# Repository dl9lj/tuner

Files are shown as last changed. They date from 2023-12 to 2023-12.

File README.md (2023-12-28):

# tuner
wireless remote control for different antenna tuners

Yaesu FC-1000 / FC-800
started with buying a Yaesu Automatic Antenna Tuner FC-1000 w/o control unit. I started with removing the existing controller and thought about to do a replacement with an atmega328p in combination with 3 HC595 shift register. Interface to a laptop pc via uart. I had this setup running (328p firmware in C). But after working with NRF24L01 modules I decided to do the interface wireless. 328p is no longer required but the 595 board can be used.The 3 HC595 are connected via wires and DSUB9 connector to an externel arduino with NRF24L01 module. I wrote a python script with slider and radio buttons. Best band settings were programmed to radio buttons of the script. Later I found out, that my FT-840 has a controller included and I only need to have a cable... But the new setup is more flexible and can be used with any transceiver. 

LDG AT-1000 (2003)
is a asymmetric low-pass 1kW antenna tuner with manual control. Automatic does not really work well and the tuner had some issues with internal EMC. But in general it has good L and C components an uses an Allegro UCN5832 to control the 15 relays. Allegro UCN5832 has an 3-wire interface similar to SPI (data, clock, strobe). Some housings have a hole for D-SUB9 connector, but I have not found an controller option. I have have removed the connection between MC68HC11 and UCN5832 (chokes L11, L12 and L13) and connected UCN5832 with wires to a DSUB9 connector (data, clock, strobe, gnd, 12V). 

Christian Koppler (DL3LAC)
is a symmetric antenna coupler. The main unit contains only L, C and relays and will be controlled with a control unit via a 25-wire cable (16 pins for relays, 7 pins for 12V, 2 pins spare). I have created an interface board with TI TPIC6B595 driver 2s (2p for inductor relays) and 5V Supply. A arduino uno with NRF24L01 will be connected to this interface for receiving control data from the NRF24L01 transmitter.

The NRF24L01 transmitter will be the same for all 3 antenna tuners. NRF24L01 receiver hardware is equal for Yaesu and Christian Koppler. LDG needs a Strobe signal from pin 3 of the arduino. It is not required to build up 3 receiver but a dedicated receiver for each tuner helps to keep the overview. Each receiver requires a separate arduino firmware. 

Software is written very straight forward (no error correction / udp style). GUI does not show the real state after start (only after pushing the button). After start you have to press the "AllOff" button to set everything to zero/off.Terminal shows the output sequence. 

Additional interface hardware is required for Yaesu and Christian Koppler. The schematics for the Yaesu tuner has an wrong order for the relays connected to pin 12 to 19 (RL11,10,9,8,7,6,5,1_2 would be better). Later I have fixed that mistake with jumper wires. In between I have used a python script with LUT to do the correction  but correction in hardware makes programming easier. U1 of the Christian Koppler interface needs a 2nd TPIC6B595 on top (all pins connected except pin18 (nc)) because current output of a single chip is too weak for driving 4 relays in parallel. The board of the LDG Tuner has already the Allegro UCN5832 shift-register which can directly connected to the external arduino. Please check wiring.txt file for connections (is more recent than the existing schematics).

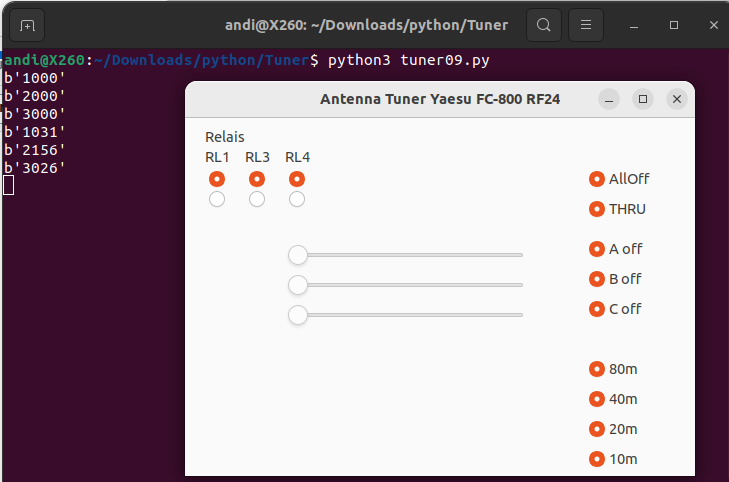
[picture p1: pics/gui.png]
J12


#### GUI
- simple GUI with wxPython
- start with "AllOff" and set all buttons to 0
- output data will be printed on the terminal window

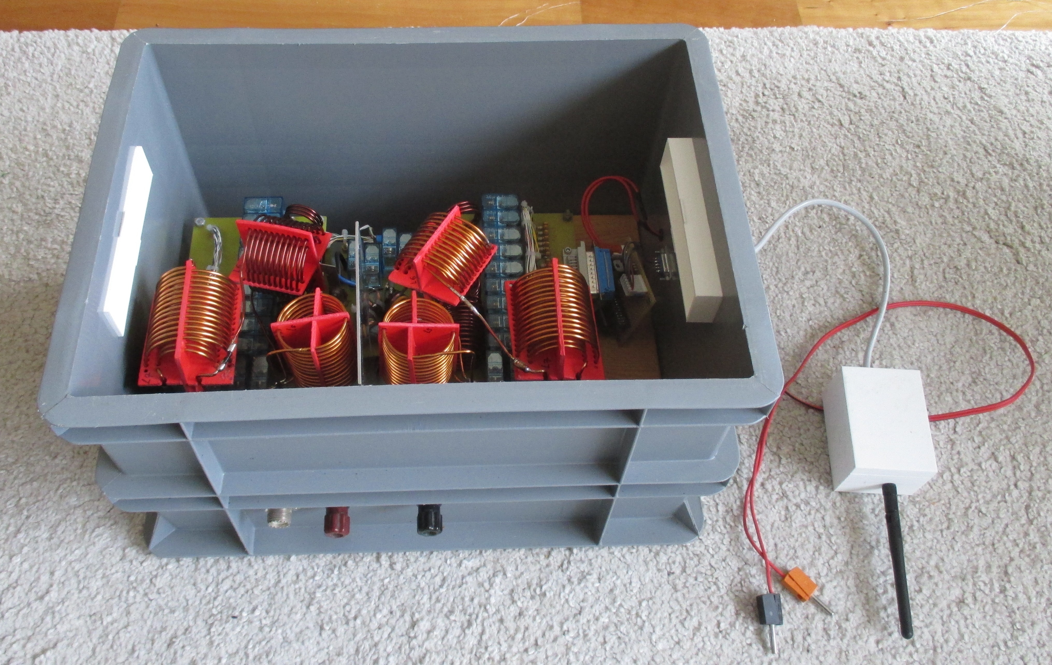
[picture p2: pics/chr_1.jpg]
J13


#### Christian Koppler with remote receiver (Arduino with NRF24L01 module)
- this euro box can be put with some rain protection in the backyard to connect the antenna
- 12V from VRLA battery will be used

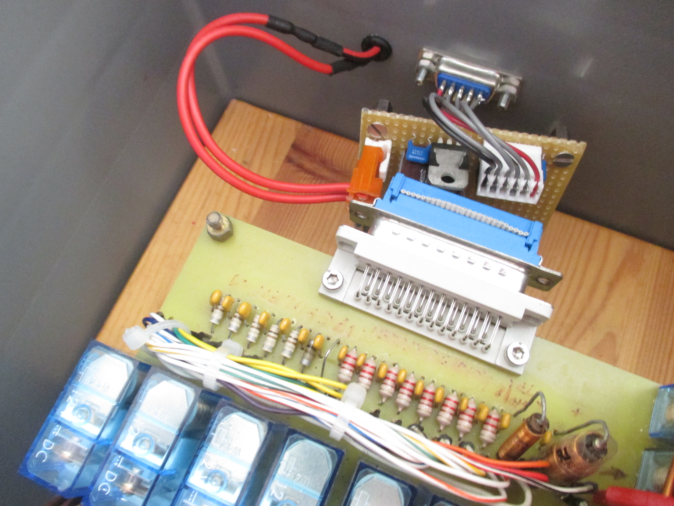
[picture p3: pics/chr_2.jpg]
J14


#### Interface inside the housing
- tuner pcb has a male DSUB25 connector

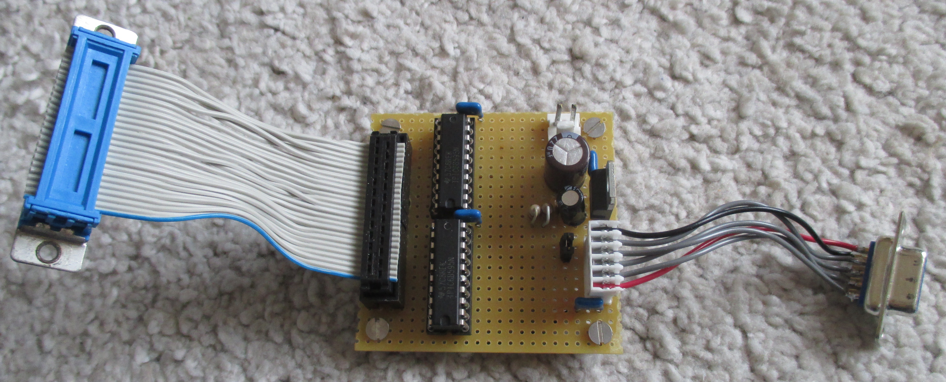
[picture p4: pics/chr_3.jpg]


#### Interface board for Christian Koppler
- with 5V supply fot TPIC6B595 components
- 2nd TPIC6B595 is soldered on top of U1 (pin 18 not connected)

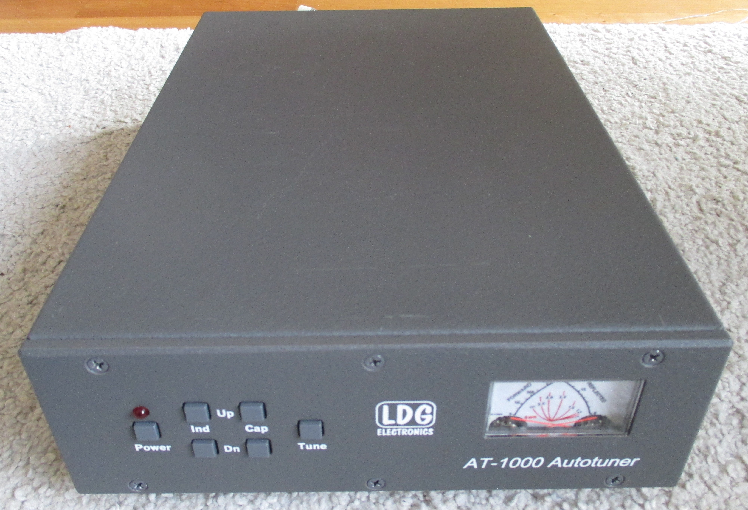
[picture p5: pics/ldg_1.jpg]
J16


#### LDG AT-1000 Tuner
- front view

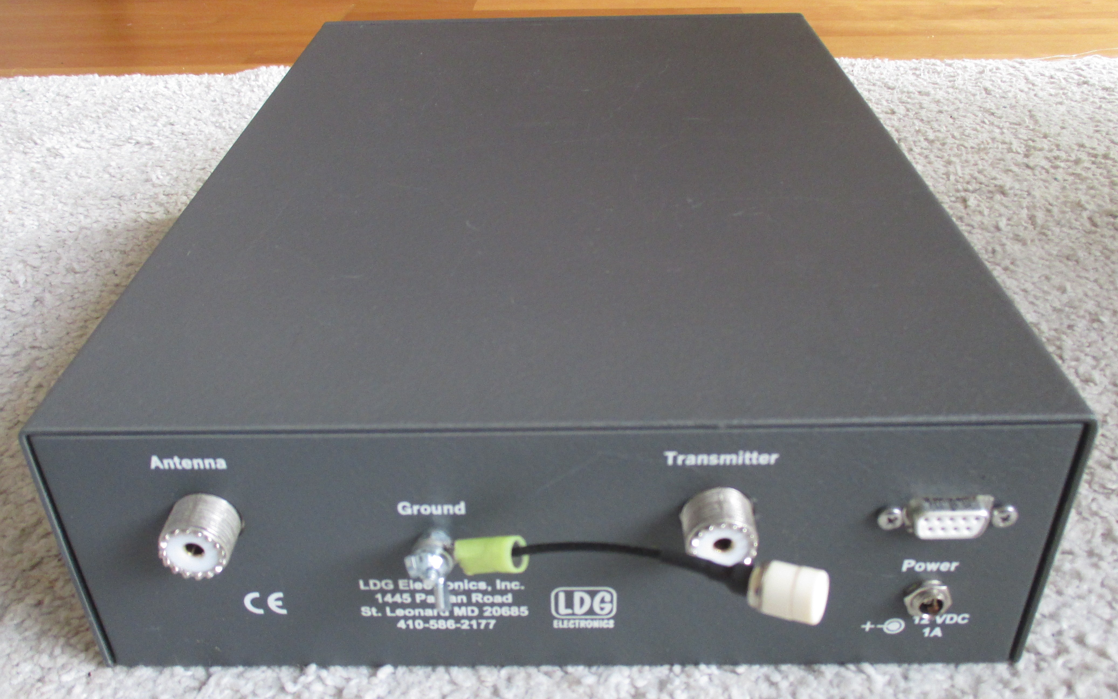
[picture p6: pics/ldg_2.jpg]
J17


#### LDG AT-1000 Tuner
- rear view with added DSUB9 female

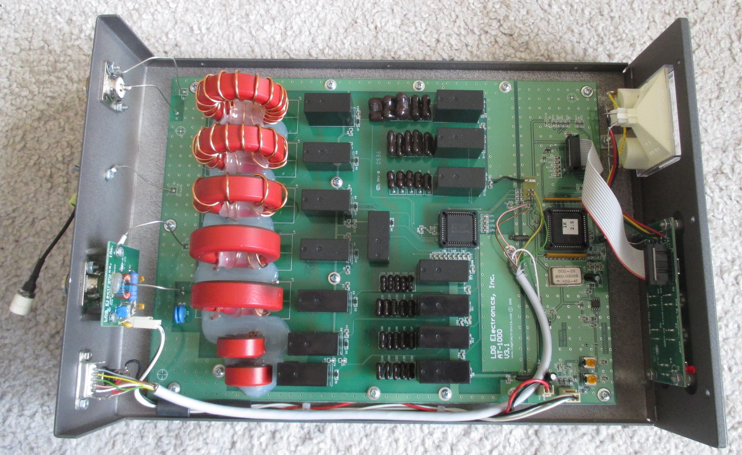
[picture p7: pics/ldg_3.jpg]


#### LDG AT-1000 Tuner
- top view
- see wiring to connect Allegro UCN5832

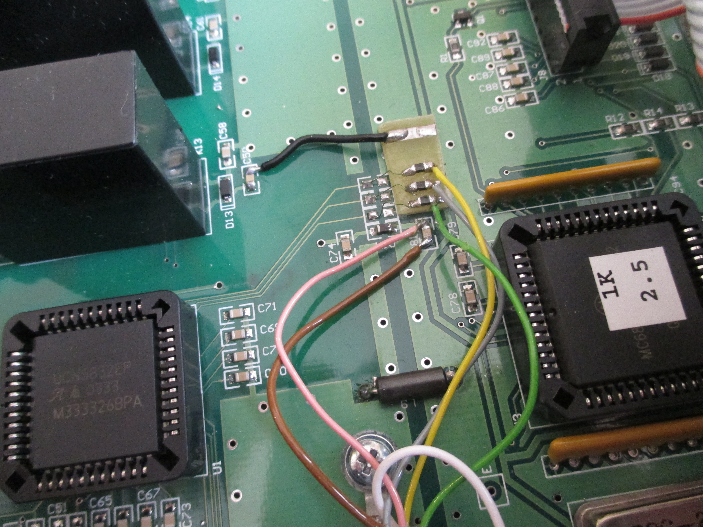
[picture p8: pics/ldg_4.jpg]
J18


#### LDG AT-1000 Tuner
- small pcb with chokes to connect Allegro UCN5832

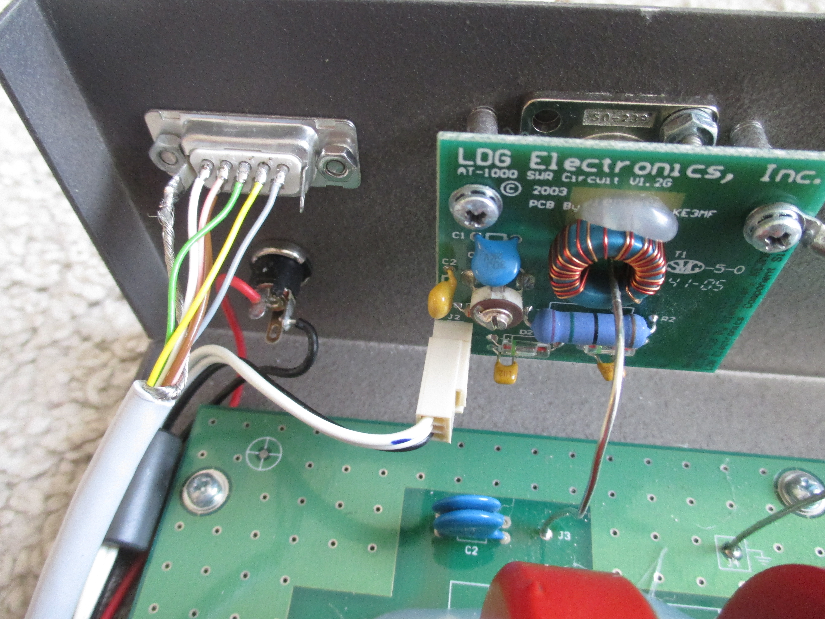
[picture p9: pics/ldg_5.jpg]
J19


#### LDG AT-1000 Tuner
- wiring / connection

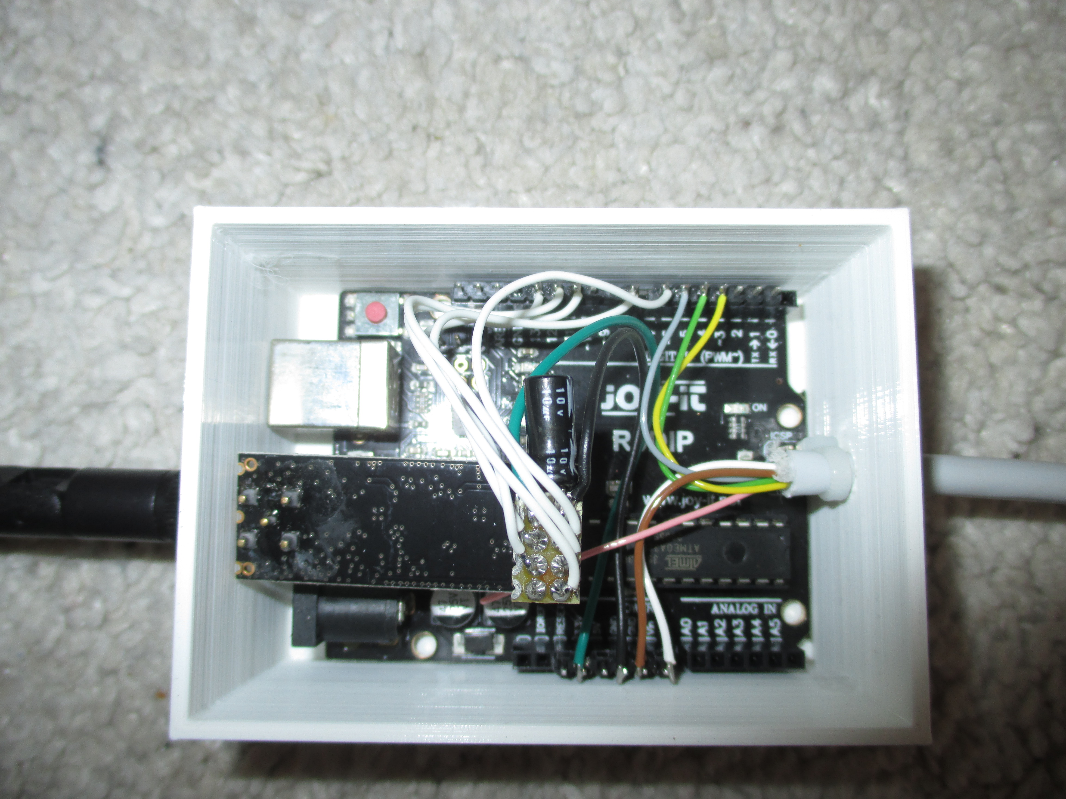
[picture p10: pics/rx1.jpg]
J20


#### Receiver box
- Arduino Uno with NRF24L01 module
- Yaesu and Christian Koppler can use the same hardware (Arduino pins 4,5,6) but need different code
- LDG uses Arduino pins 3,4,5

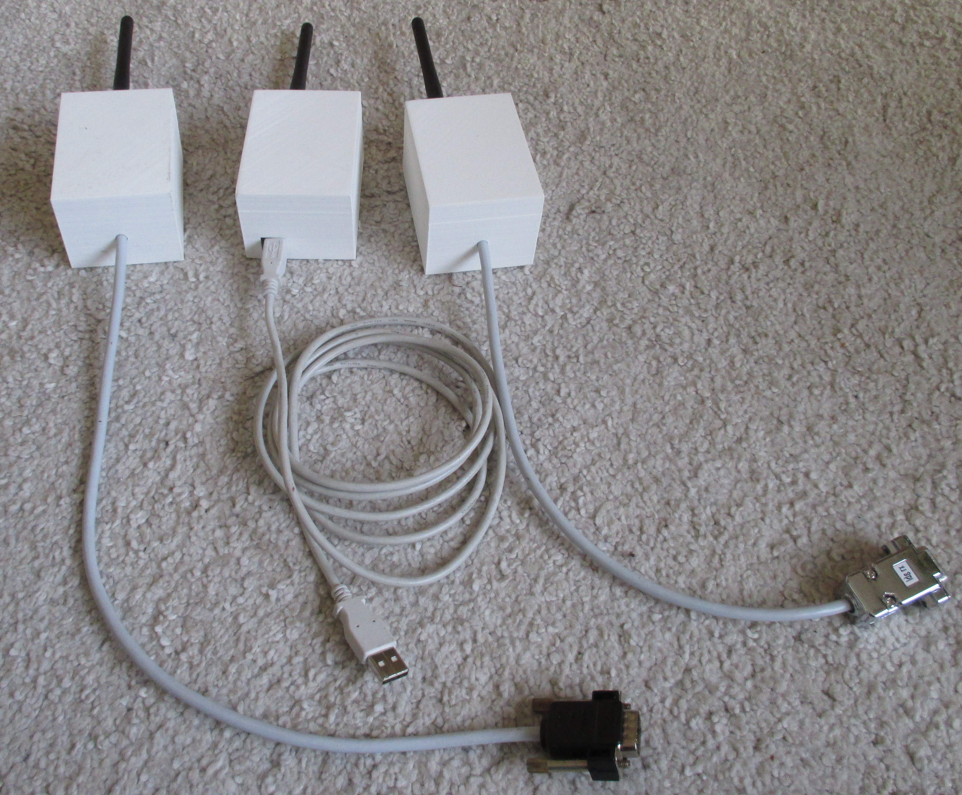
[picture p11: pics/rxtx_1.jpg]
J21


#### Receiver and transmitter boxes 
- looking very similar

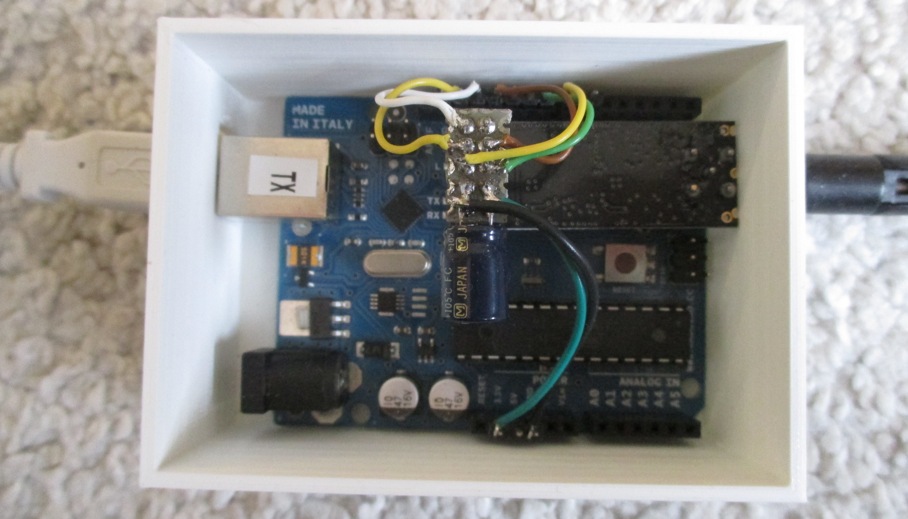
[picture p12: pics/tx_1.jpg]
J22


#### Transmitter box
- has USB connector for the connection to a laptop pc
- can also act w/o pc (currently only for testing) 

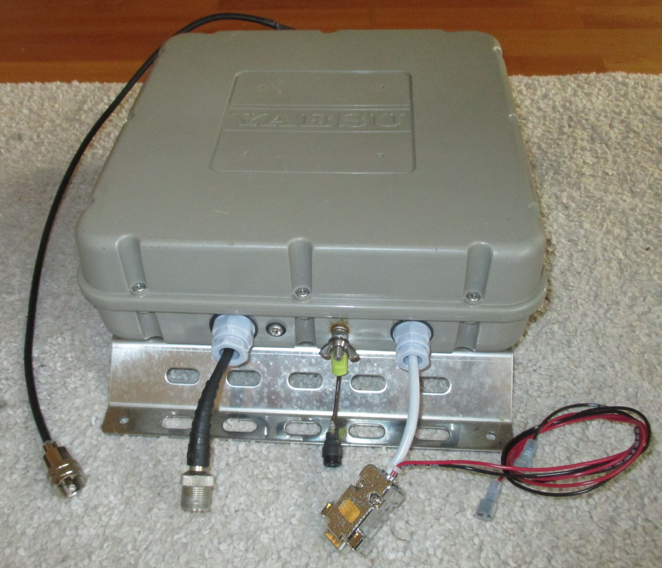
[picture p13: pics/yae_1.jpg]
J23


#### Yaesu FC-1000 Antenna Tuner
- top view
- housing can withstand some raindrops

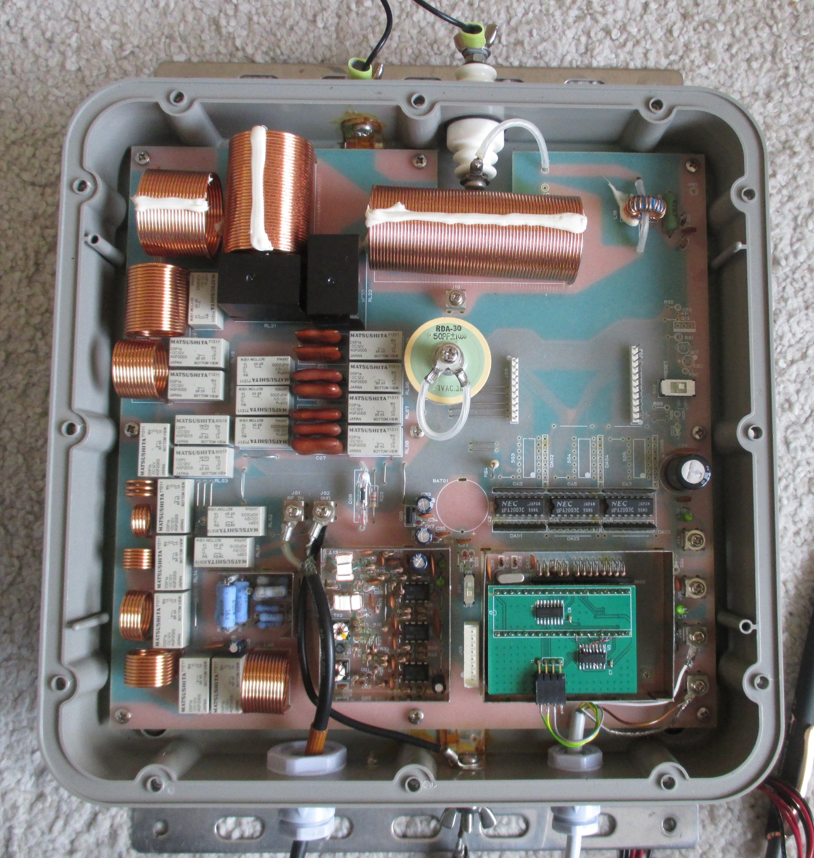
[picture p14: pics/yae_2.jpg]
J24


#### Yaesu FC-1000 Antenna Tuner
- nice device - 40pin controller were replaced with a small pcp (3 x HC595)
- 3 sections can nearly tune and match any antenna (up to 150W)

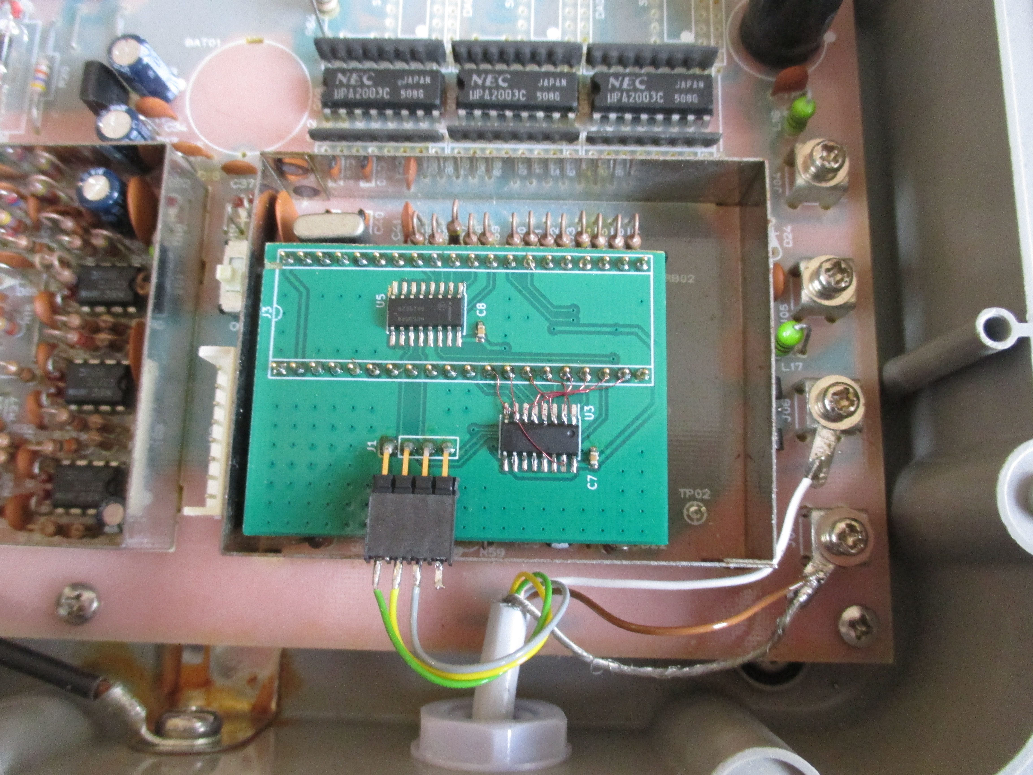
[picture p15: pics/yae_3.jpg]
J25


#### Yaesu FC-1000 interface board
- see wiring

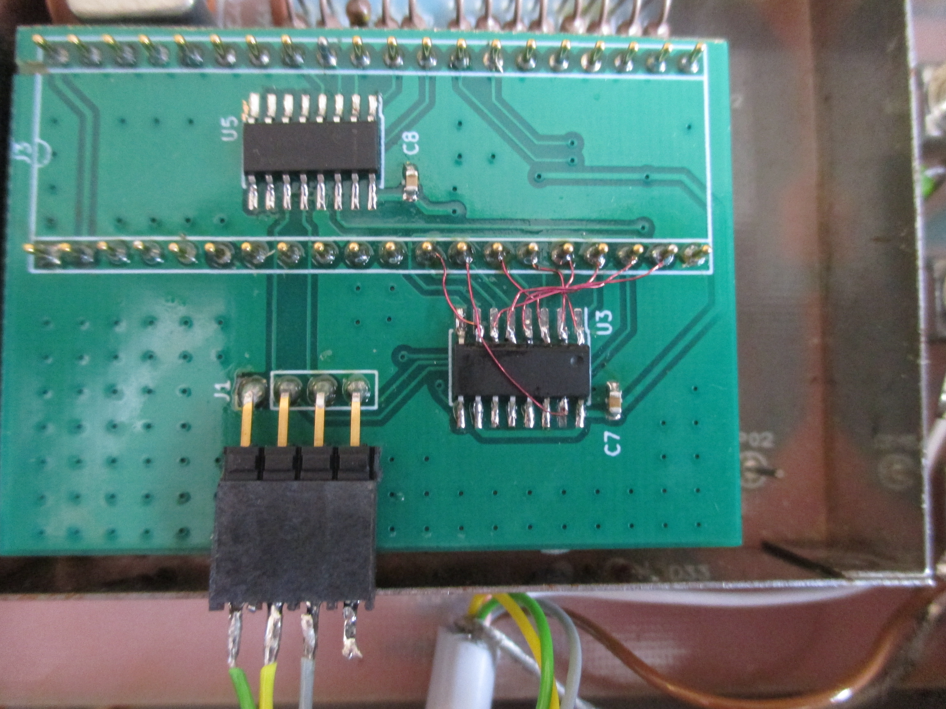
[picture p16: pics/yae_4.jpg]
J26


#### Yaesu FC-1000 interface board
- error was corrected with jumper wires

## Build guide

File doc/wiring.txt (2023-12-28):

This is the leading document for wiring. 2023-12-28

During development wiring sometimes changes. Wrong schematics, mixing connectors (female / male)
sometimes leads to different pin numbers. Schematics will not be updated immediately. So I have
checked again all connections and wrote the result to this document.

While making pictures I found out, that I also had fixed the mixedup pins on the yaesu interface
board. So the python script does not longer need the LUT. This helps me to avoid I will get some 
mixup in my brain.

1. Connecting RF24 to Arduino Uno is in all applications (rx/tx) the same.
Check where GND is and start wiring. A 10uF elcap is required (3V3 to GND).
I have added 100nF in parallel.

12 --o o--nc
13 --o o--11
 7 --o o-- 8
GND--o o--3V3

2. Arduino Rx for LDG (Arduino --- DSUB9 male)
Vin -- wh --- 1
GND -- bn --- 6
3 ---- gr --- 5 STROBE
4 ---- ye --- 4 SCLK
5 ---- gn --- 3 MOSI
nc --- rs --- 2 (not used)

3. Arduino Rx for Christian Koppler (Arduino --- DSUB9 male)
Vin -- wh --- 1
GND -- bn --- 6
6 ---- gr --- 5 SS
4 ---- ye --- 4 SCLK
5 ---- gn --- 3 MOSI
nc --- rs --- 2 (not used)

4. Arduino Rx for Yaesu Tuner (Arduino --- DSUB9 male)
Vin -- wh --- 1
GND -- bn --- 6
6 ---- gr --- 5 LATCH
4 ---- ye --- 4 SCLK
5 ---- gn --- 3 MOSI
nc --- rs --- 2 (not used)

5. Christian Koppler interface U1/U2 to 26p 2row connector
x----26 o o 25 -- 1.6
1.5--24 o o 23 -- 1.7
1.4--22 o o 21 -- 1.14
x----20 o o 19 -- 1.15
x----18 o o 17 -- 1.16
12V--16 o o 15 -- 2.4
12V--14 o o 13 -- 2.5
12V--12 o o 11 -- 2.6
12V--10 o o 9 --- 2.7
12V---8 o o 7 --- 2.14
12V---6 o o 5 --- 2.15
12V---4 o o 3 --- 2.16
1.17--2 o o 1 --- 2.17

6. Christian Koppler interface MTA100 to DSUB9 female
12V  1 --rd-- 6
MOSI 2 ------ 2
SCK  3 ------ 5
SS   4 ------ 4
OE   5 ------ 3 (connected to GND (J1))
GND  6 --bk-- 1

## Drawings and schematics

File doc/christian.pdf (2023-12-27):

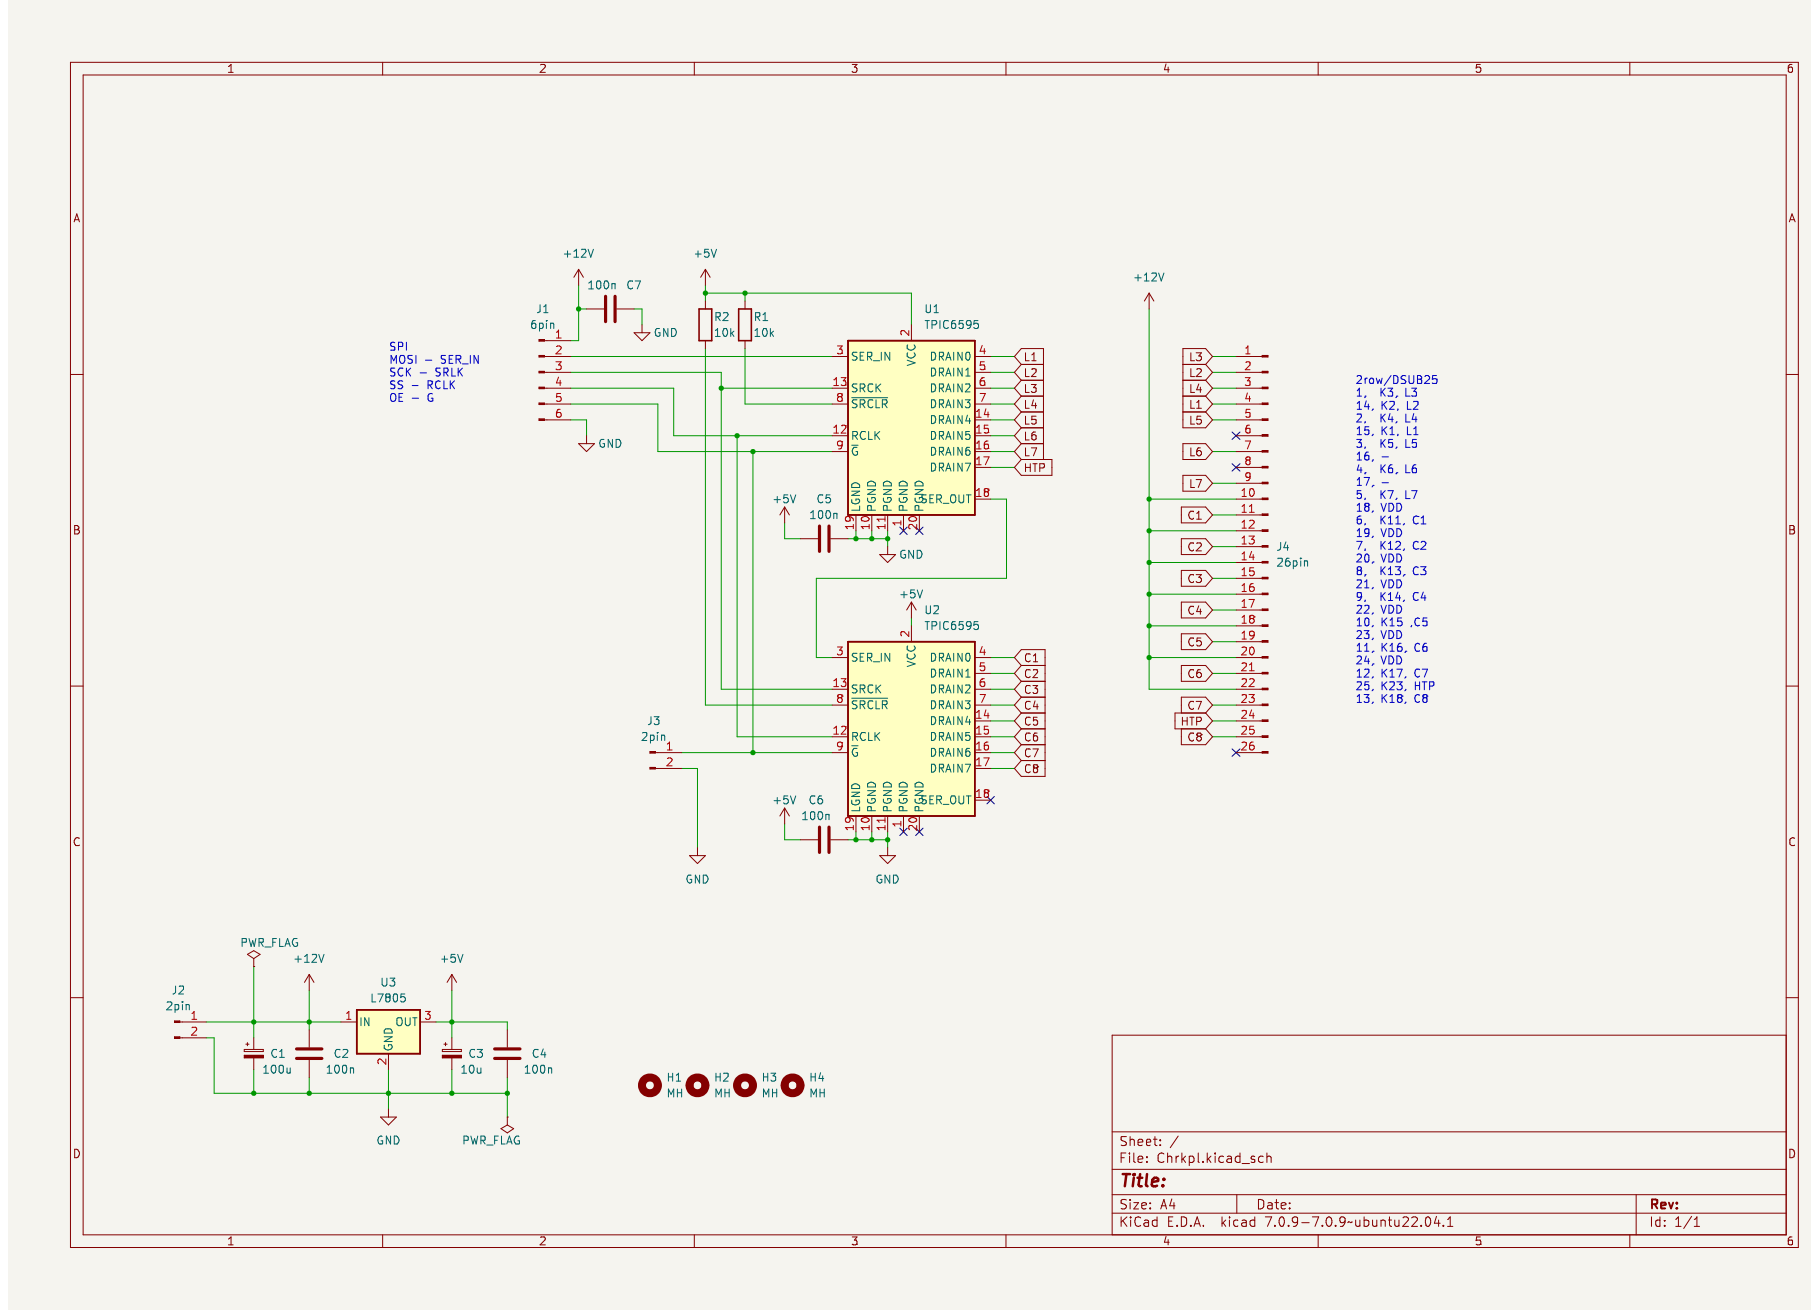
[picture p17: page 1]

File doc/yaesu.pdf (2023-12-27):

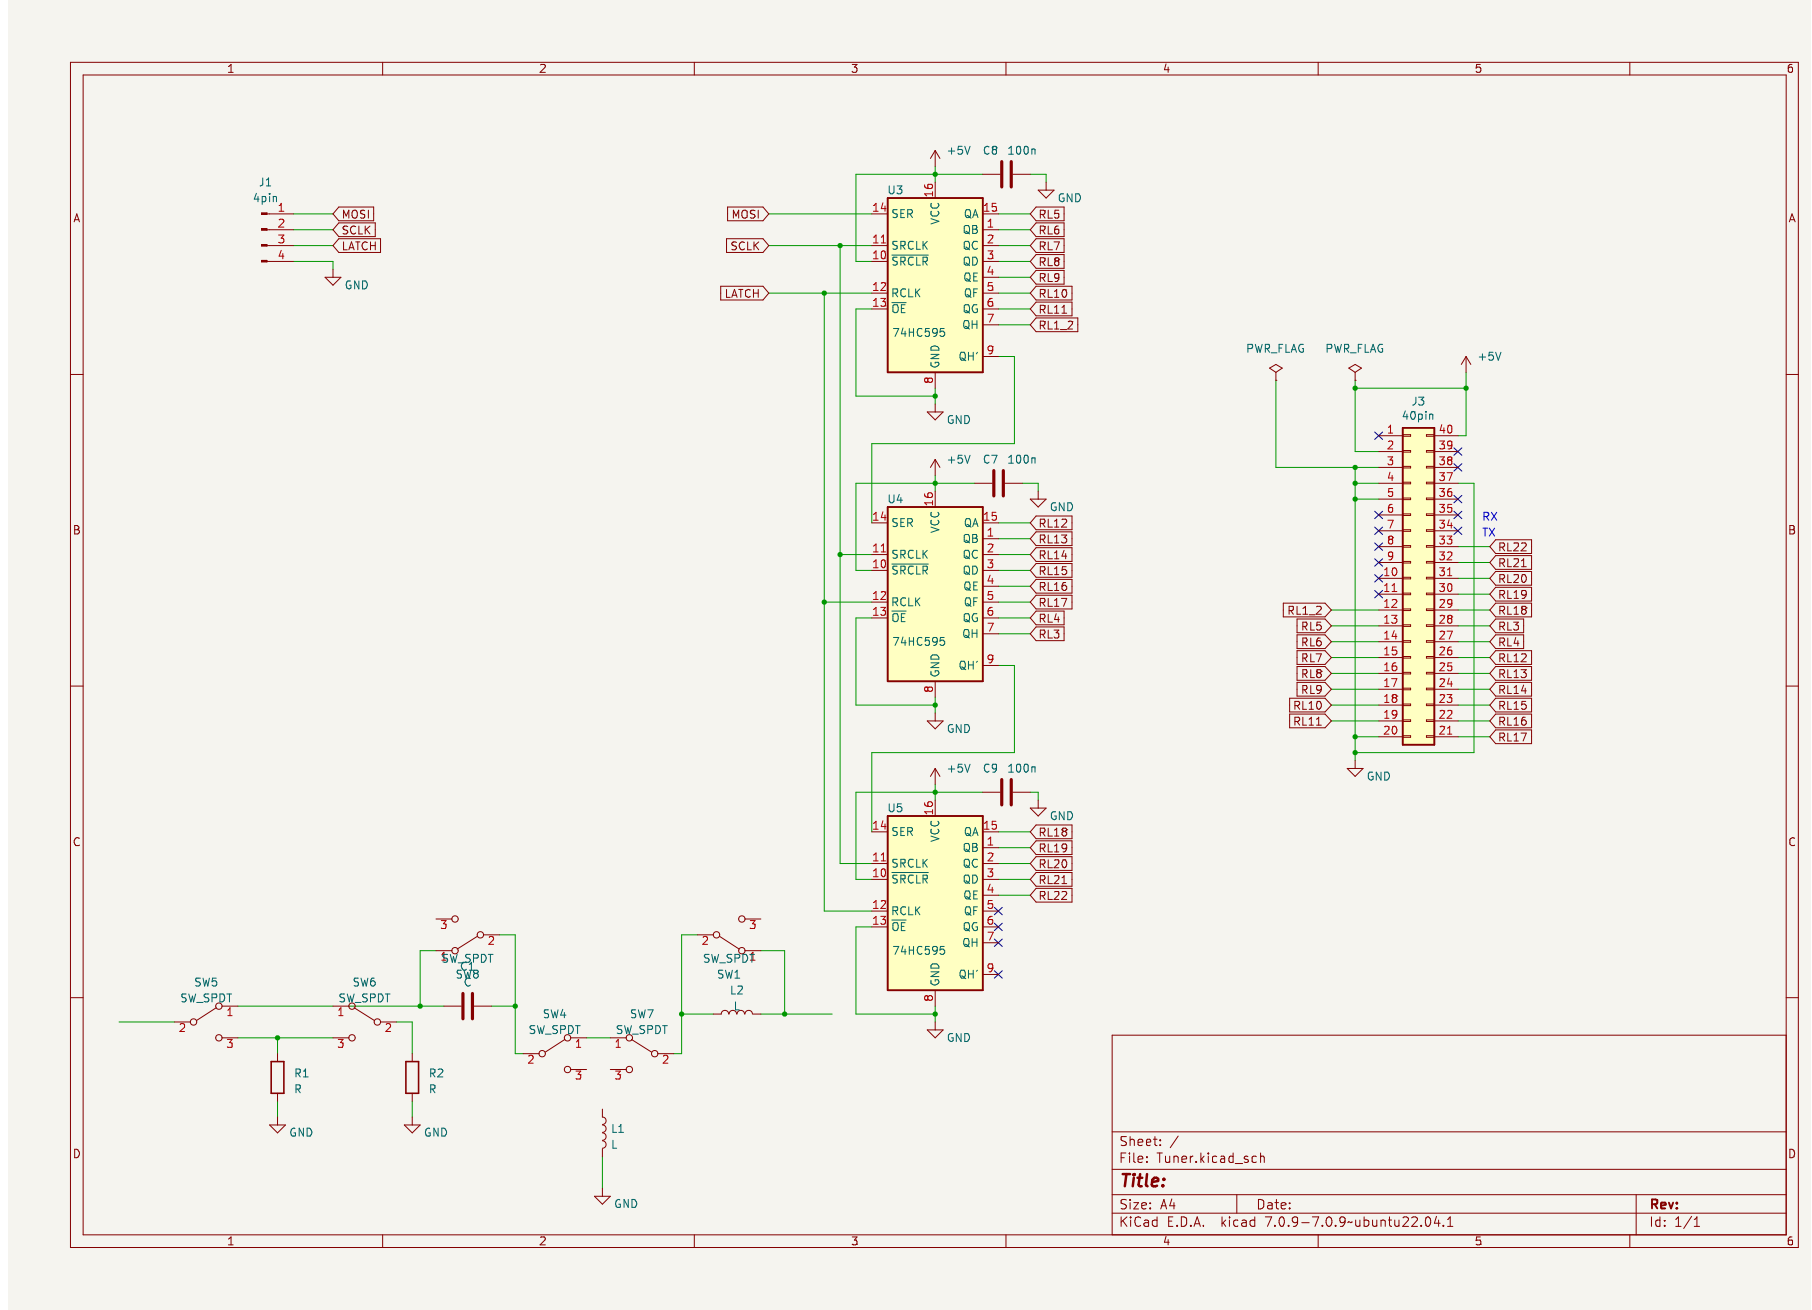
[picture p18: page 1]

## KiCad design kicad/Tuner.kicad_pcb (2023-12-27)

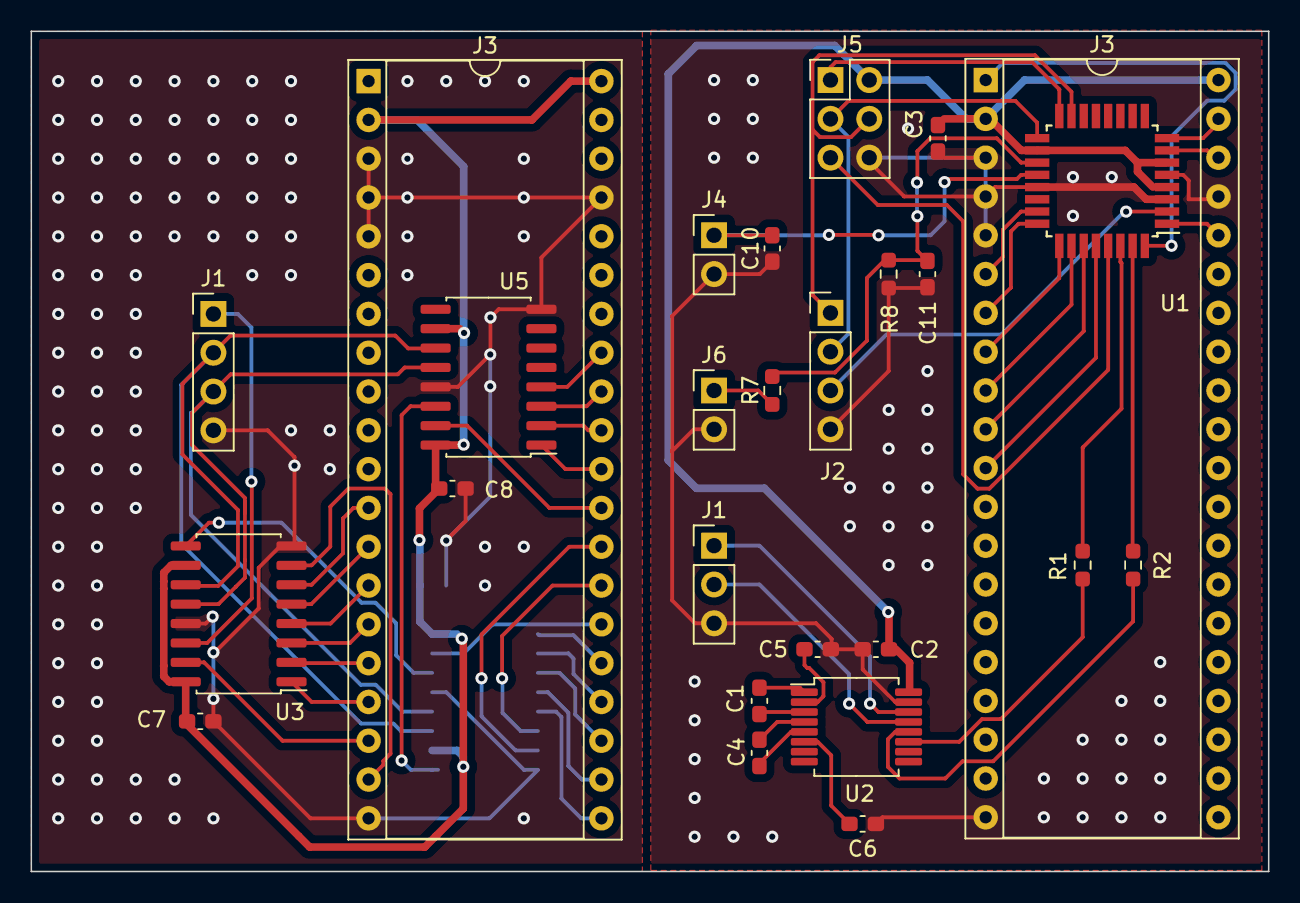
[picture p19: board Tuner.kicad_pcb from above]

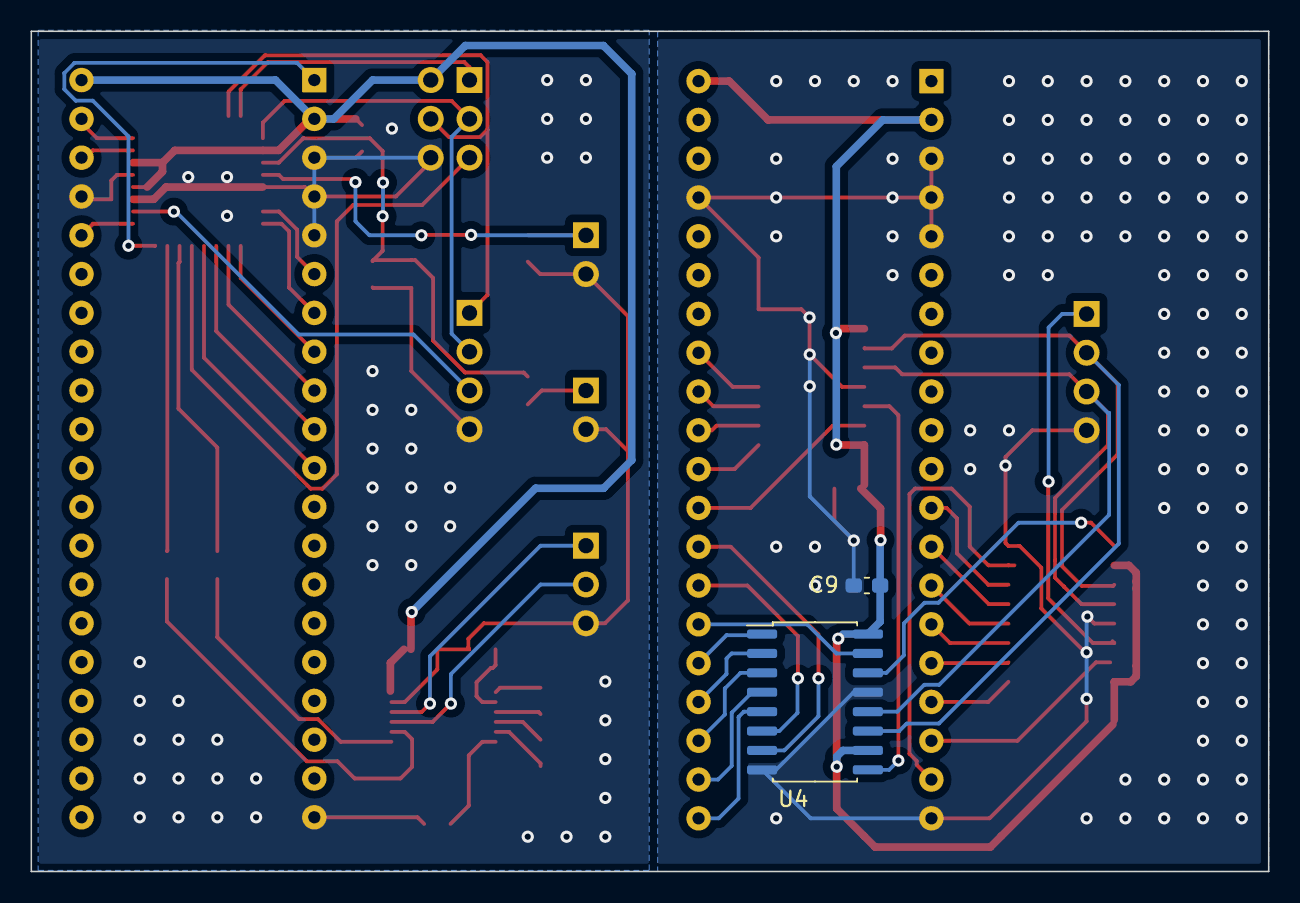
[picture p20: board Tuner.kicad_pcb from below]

Board: 2 copper layers, 81.0 x 55.0 mm, 28 parts (2 on the bottom side), 28 nets.

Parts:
C1, C2, C3, C4, C5, C6, C7, C8, C9, C10, C11: 100n; C_0603_1608Metric_Pad1.08x0.95mm_HandSolder
J1: 3pin; PinHeader_1x03_P2.54mm_Vertical
J1#2, J2: 4pin; PinHeader_1x04_P2.54mm_Vertical
J3, J3#2: 40pin; DIP-40_W15.24mm_Socket
J4, J6: 2pin; PinHeader_1x02_P2.54mm_Vertical
J5: 2x3pin; PinHeader_2x03_P2.54mm_Vertical
R1, R2, R7, R8: 10k; R_0603_1608Metric_Pad0.98x0.95mm_HandSolder
U1: ATmega328PB-A; TQFP-32_7x7mm_P0.8mm
U2: MAX232; SSOP-16_5.3x6.2mm_P0.65mm
U3, U4, U5: 74HC595; SO-16_5.3x10.2mm_P1.27mm

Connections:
+5V: C2.2, C3.1, C7.1, C8.1, C9.1, J3.2, J3.40, J3#2.2, J3#2.40, J5.2, U1.4 (VCC), U1.6 (PE1), U1.18 (AVCC), U2.16 (VCC), U3.10 (~SRCLR), U3.16 (VCC), U4.10 (~SRCLR), U4.16 (VCC), U5.10 (~SRCLR), U5.16 (VCC)
GND: C2.1, C3.2, C5.2, C6.2, C7.2, C8.2, C9.2, C10.1, C11.2, J1.3, J1#2.4, J2.4, J3.3, J3.4, J3.5, J3.20, J3.37, J3#2.3, J3#2.4, J3#2.5, J3#2.20, J3#2.37, J4.2, J5.6, J6.2, R8.1, U1.3 (PE0), U1.5 (GND), U1.21 (GND), U2.15 (GND), U3.8 (GND), U3.13 (~OE), U4.8 (GND), U4.13 (~OE), U5.8 (GND), U5.13 (~OE)
LATCH: J1#2.3, J2.3, U1.2 (PD4), U3.12 (RCLK), U4.12 (RCLK), U5.12 (RCLK)
MOSI: J1#2.1, J2.1, J5.4, U1.15 (PB3), U3.14 (SER)
unnamed: U3.9 (QH'), U4.14 (SER)
unnamed: U4.9 (QH'), U5.14 (SER)
RL1_2: J3#2.19, U3.7 (QH)
RL3: J3#2.28, U4.7 (QH)
RL4: J3#2.27, U4.6 (QG)
RL5: J3#2.18, U3.15 (QA)
RL6: J3#2.17, U3.1 (QB)
RL7: J3#2.16, U3.2 (QC)
RL8: J3#2.15, U3.3 (QD)
RL9: J3#2.14, U3.4 (QE)
RL10: J3#2.13, U3.5 (QF)
RL11: J3#2.12, U3.6 (QG)
RL12: J3#2.26, U4.15 (QA)
RL13: J3#2.25, U4.1 (QB)
RL14: J3#2.24, U4.2 (QC)
RL15: J3#2.23, U4.3 (QD)
RL16: J3#2.22, U4.4 (QE)
RL17: J3#2.21, U4.5 (QF)
RL18: J3#2.29, U5.15 (QA)
RL19: J3#2.30, U5.1 (QB)
RL20: J3#2.31, U5.2 (QC)
RL21: J3#2.32, U5.3 (QD)
RL22: J3#2.33, U5.4 (QE)
SCLK: J1#2.2, J2.2, J5.3, U1.17 (PB5), U3.11 (SRCLK), U4.11 (SRCLK), U5.11 (SRCLK)

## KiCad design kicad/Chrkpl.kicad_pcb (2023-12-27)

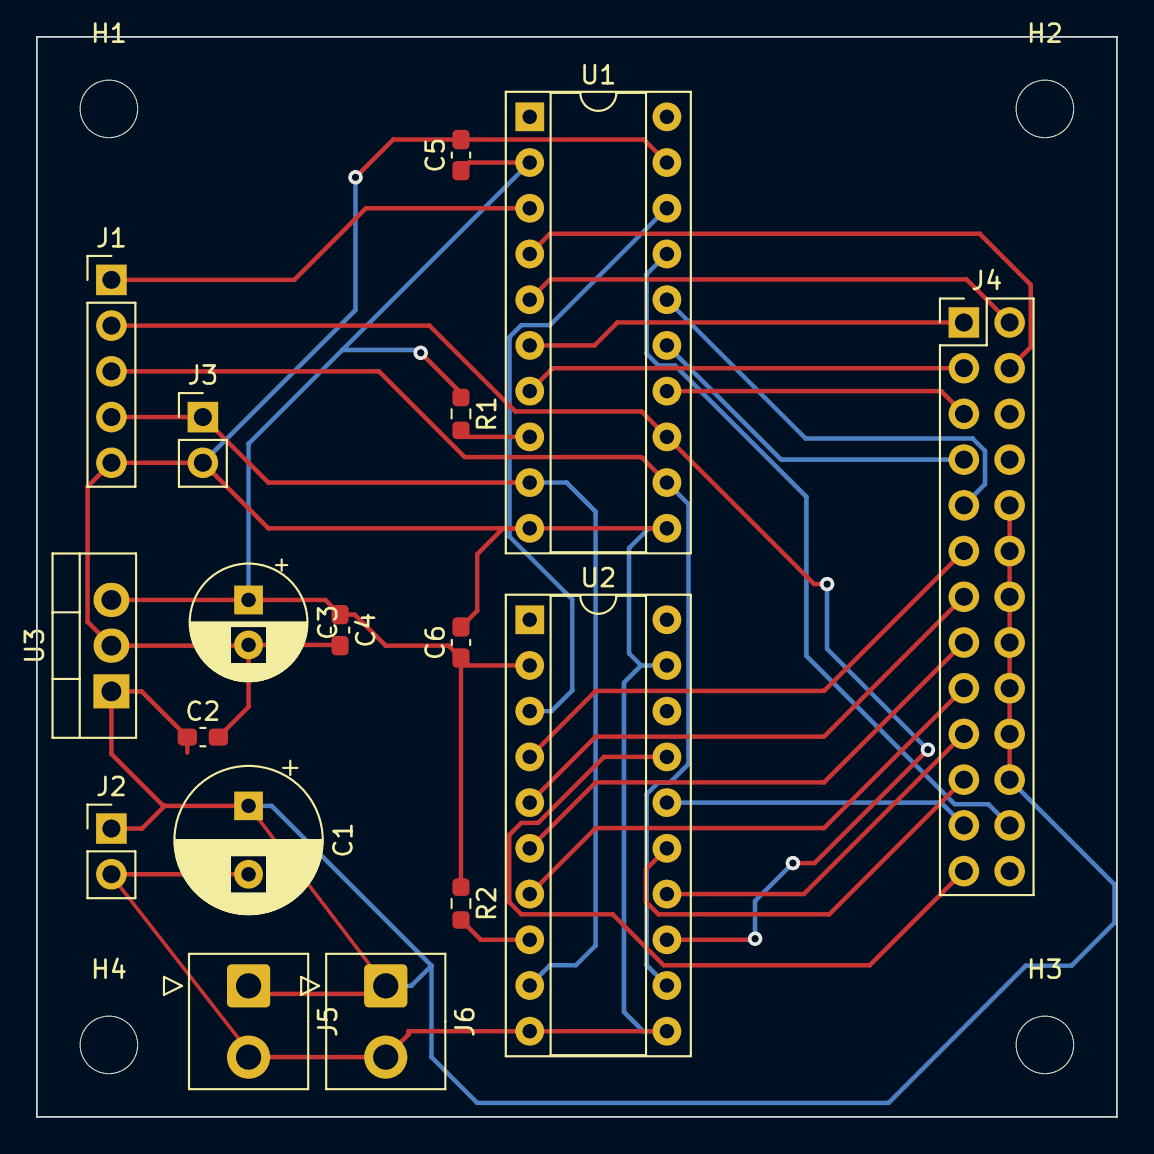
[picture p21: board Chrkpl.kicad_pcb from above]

Board: 2 copper layers, 60.0 x 60.0 mm, 21 parts (0 on the bottom side), 26 nets.

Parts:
C1: 100u; CP_Radial_D8.0mm_P3.80mm
C2, C4, C5, C6: 100n; C_0603_1608Metric_Pad1.08x0.95mm_HandSolder
C3: 10u; CP_Radial_D6.3mm_P2.50mm
H1, H2, H3, H4: MH; MountingHole_3.2mm_M3
J1: 5pin; PinHeader_1x05_P2.54mm_Vertical
J2, J3: 2pin; PinHeader_1x02_P2.54mm_Vertical
J4: 26pin; PinHeader_2x13_P2.54mm_Vertical
J5, J6: 2pin; TE_826576-2_1x02_P3.96mm_Vertical
R1, R2: 10k; R_0603_1608Metric_Pad0.98x0.95mm_HandSolder
U1, U2: TPIC6595; DIP-20_W7.62mm_Socket
U3: L7805; TO-220-3_Vertical

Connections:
+5V: C3.1, C4.1, C5.1, C6.1, R1.1, R2.1, U1.2 (VCC), U2.2 (VCC), U3.3 (OUT)
+12V: C1.1, C2.1, J2.1, J4.10, J4.12, J4.14, J4.16, J4.18, J4.20, J4.22, J5.1, J6.1, U3.1 (IN)
C1: J4.11, U2.4 (DRAIN0)
C2: J4.13, U2.5 (DRAIN1)
C3: J4.15, U2.6 (DRAIN2)
C4: J4.17, U2.7 (DRAIN3)
C5: J4.19, U2.14 (DRAIN4)
C6: J4.21, U2.15 (DRAIN5)
C7: J4.23, U2.16 (DRAIN6)
C8: J4.25, U2.17 (DRAIN7)
GND: C1.2, C2.2, C3.2, C4.2, C5.2, C6.2, J1.5, J2.2, J3.2, J5.2, J6.2, U1.10 (PGND), U1.11 (PGND), U1.19 (LGND), U2.10 (PGND), U2.11 (PGND), U2.19 (LGND), U3.2 (GND)
HTP: J4.24, U1.17 (DRAIN7)
L1: J4.4, U1.4 (DRAIN0)
L2: J4.2, U1.5 (DRAIN1)
L3: J4.1, U1.6 (DRAIN2)
L4: J4.3, U1.7 (DRAIN3)
L5: J4.5, U1.14 (DRAIN4)
L6: J4.7, U1.15 (DRAIN5)
L7: J4.9, U1.16 (DRAIN6)
unnamed: J1.1, U1.3 (SER_IN)
unnamed: J1.2, U1.13 (SRCK), U2.13 (SRCK)
unnamed: J1.3, U1.12 (RCLK), U2.12 (RCLK)
unnamed: J1.4, J3.1, U1.9 (~G), U2.9 (~G)
unnamed: U1.18 (SER_OUT), U2.3 (SER_IN)
unnamed: R1.2, U1.8 (~SRCLR)
unnamed: R2.2, U2.8 (~SRCLR)

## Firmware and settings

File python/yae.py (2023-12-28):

#!/usr/bin/python
# -*- coding: utf-8 -*-

import wx
import serial
import socket
#import time
from array import *

# UDP_IP="192.168.2.144" #PC
# UDP_IPT="192.168.2.139" #Arduino
# UDP_PORT=8883

# sock = socket.socket( socket.AF_INET, # Internet
#                       socket.SOCK_DGRAM ) # UDP
# sock.bind( (UDP_IP,UDP_PORT) )

ser = serial.Serial('/dev/ttyACM0', 9600, timeout=2)
# ser.open()
# ser.write("C255;0;0")
# ser.close()

class Example(wx.Frame):
           
    def __init__(self, *args, **kw):
        super(Example, self).__init__(*args, **kw) 
        self.InitUI()
        
    def InitUI(self):   
            
        pnl = wx.Panel(self)
        self.a = wx.StaticText(pnl, label='Relais', pos=(20, 10))  
        self.a = wx.StaticText(pnl, label='RL1', pos=(20, 30))  
        self.a = wx.StaticText(pnl, label='RL3', pos=(60, 30))  
        self.a = wx.StaticText(pnl, label='RL4', pos=(100, 30))  
        
        self.ra1 = wx.RadioButton(pnl,  pos=(20, 50), 
            style=wx.RB_GROUP)
        self.ra2 = wx.RadioButton(pnl,  pos=(20, 70))
        self.ra1.Bind(wx.EVT_RADIOBUTTON, self.OnPointA)
        self.ra2.Bind(wx.EVT_RADIOBUTTON, self.OnPointA)

        self.rb1 = wx.RadioButton(pnl,  pos=(60, 50), 
            style=wx.RB_GROUP)
        self.rb2 = wx.RadioButton(pnl,  pos=(60, 70))
        self.rb1.Bind(wx.EVT_RADIOBUTTON, self.OnPointB)
        self.rb2.Bind(wx.EVT_RADIOBUTTON, self.OnPointB)

        self.rc1 = wx.RadioButton(pnl,  pos=(100, 50), 
            style=wx.RB_GROUP)
        self.rc2 = wx.RadioButton(pnl,  pos=(100, 70))
        self.rc1.Bind(wx.EVT_RADIOBUTTON, self.OnPointC)
        self.rc2.Bind(wx.EVT_RADIOBUTTON, self.OnPointC)

      


        slda = wx.Slider(pnl, value=0, minValue=0, maxValue=127, pos=(100, 120), 
            size=(250, -1), style=wx.SL_HORIZONTAL)
            
        slda.Bind(wx.EVT_SCROLL, self.OnSliderScrollA)
            
        sldb = wx.Slider(pnl, value=0, minValue=0, maxValue=63, pos=(100, 150), 
            size=(250, -1), style=wx.SL_HORIZONTAL)    
        
        sldb.Bind(wx.EVT_SCROLL, self.OnSliderScrollB)

        sldc = wx.Slider(pnl, value=0, minValue=0, maxValue=31, pos=(100, 180), 
            size=(250, -1), style=wx.SL_HORIZONTAL)    
        
        sldc.Bind(wx.EVT_SCROLL, self.OnSliderScrollC)        

        self.rr1 = wx.RadioButton(pnl, label='A off', pos=(400, 120), 
            style=wx.RB_GROUP)
        self.rr1.Bind(wx.EVT_RADIOBUTTON, self.OnPointR1)
        
        self.rr2 = wx.RadioButton(pnl, label='B off', pos=(400, 150),
			style=wx.RB_GROUP)
        self.rr2.Bind(wx.EVT_RADIOBUTTON, self.OnPointR2)

        self.rr3 = wx.RadioButton(pnl, label='C off', pos=(400, 180),
			style=wx.RB_GROUP)
        self.rr3.Bind(wx.EVT_RADIOBUTTON, self.OnPointR3)


        self.rr4 = wx.RadioButton(pnl, label='AllOff', pos=(400, 50),
			style=wx.RB_GROUP)
        self.rr4.Bind(wx.EVT_RADIOBUTTON, self.OnPointR4)

        self.rr5 = wx.RadioButton(pnl, label='THRU', pos=(400, 80),
			style=wx.RB_GROUP)
        self.rr5.Bind(wx.EVT_RADIOBUTTON, self.OnPointR5)

        self.rr6 = wx.RadioButton(pnl, label='80m', pos=(400, 240),
			style=wx.RB_GROUP)
        self.rr6.Bind(wx.EVT_RADIOBUTTON, self.OnPointR6)

        self.rr7 = wx.RadioButton(pnl, label='40m', pos=(400, 270),
			style=wx.RB_GROUP)
        self.rr7.Bind(wx.EVT_RADIOBUTTON, self.OnPointR7)

        self.rr8 = wx.RadioButton(pnl, label='20m', pos=(400, 300),
			style=wx.RB_GROUP)
        self.rr8.Bind(wx.EVT_RADIOBUTTON, self.OnPointR8)

        self.rr9 = wx.RadioButton(pnl, label='10m', pos=(400, 330),
			style=wx.RB_GROUP)
        self.rr9.Bind(wx.EVT_RADIOBUTTON, self.OnPointR9)
                
        self.SetSize((510, 400))
        self.SetTitle('Antenna Tuner Yaesu FC-800 RF24')
        self.Centre()
        self.Show(True)     

        
    def OnPointA(self, e):
        if self.ra1.GetValue(): val = 128
        if self.ra2.GetValue(): val = 0
        #print val
        self.g = val
        self.Tune()
        
    def OnPointB(self, e):
        if self.rb1.GetValue(): val = 128
        if self.rb2.GetValue(): val = 0
        #print val
        self.h = val
        self.Tune()
        
    def OnPointC(self, e):
        if self.rc1.GetValue(): val = 64
        if self.rc2.GetValue(): val = 0
        #print val
        self.i = val
        self.Tune()



    def OnSliderScrollA(self, e):
        obj = e.GetEventObject()
        val = obj.GetValue()
        #val = val + 128
        #val = LUT[val]
        #val = val >> 1
        val = val + 1000
        #print val
        self.d = val
        self.Tune()


    def OnSliderScrollB(self, e):
        obj = e.GetEventObject()
        val = obj.GetValue()
        val = val + 2000
        #print val
        self.e = val
        self.Tune()


    def OnSliderScrollC(self, e):
        obj = e.GetEventObject()
        val = obj.GetValue()
        val = val + 3000
        #print val
        self.f = val
        self.Tune()

    def OnPointR1(self, e):
        if self.rr1.GetValue(): val = 1000
        #print val
        self.d = val
        self.Tune()

    def OnPointR2(self, e):
        if self.rr2.GetValue(): val = 2000
        #print val
        self.e = val
        self.Tune()

    def OnPointR3(self, e):
        if self.rr3.GetValue(): val = 3000
        #print val
        self.f = val
        self.Tune()

    def OnPointR4(self, e):
        self.d = 1000
        self.e = 2000
        self.f = 3000
        self.g = 0
        self.h = 0
        self.i = 0
        self.k = 0
        self.l = 0
        self.j = 0
        self.Tune()

    def OnPointR5(self, e):
        self.d = 1255
        self.e = 2255
        self.f = 3255
        self.g = 0
        self.h = 0
        self.i = 0
        self.Tune()

    def OnPointR6(self, e):
        self.k = 1031
        self.l = 2156
        self.j = 3026
        self.Update()

    def OnPointR7(self, e):
        self.k = 1034
        self.l = 2170
        self.j = 3031
        self.Update()

    def OnPointR8(self, e):
        self.k = 1012
        self.l = 2121
        self.j = 3011
        self.Update()

    def OnPointR9(self, e):
        self.k = 1000
        self.l = 2000
        self.j = 3031
        self.Update()

	
    def Update(self):
        self.k = str(self.k)
        print(self.k.encode('ascii'))
        ser.write(self.k.encode('ascii'))
        self.l = str(self.l)
        print(self.l.encode('ascii'))
        ser.write(self.l.encode('ascii'))
        self.j = str(self.j)
        print(self.j.encode('ascii'))
        ser.write(self.j.encode('ascii'))
        
    def Tune(self):
        self.k = self.d + self.g
        self.l = self.e + self.h + self.i
        self.j = str(self.k)
        print(self.j.encode('ascii'))
        ser.write(self.j.encode('ascii'))
        self.j = str(self.l)
        print(self.j.encode('ascii'))
        ser.write(self.j.encode('ascii'))
        self.j = str(self.f)
        print(self.j.encode('ascii'))
        ser.write(self.j.encode('ascii'))
        
LUT = [0, 32, 16, 48, 8, 40, 24, 56, 4, 36, 20, 52, 12, 44, 28, 60, 
       2, 34, 18, 50, 10, 42, 26, 58, 6, 38, 22, 54, 14, 46, 30, 62,
       1, 33, 17, 49, 9, 41, 25, 57, 5, 37, 21, 53, 13, 45, 29, 61, 
       3, 35, 19, 51, 11, 43, 27, 59, 7, 39, 23, 55, 15, 47, 31, 63,
       128, 160, 144, 176, 136, 168, 152, 184, 132, 164, 148, 180, 140, 172, 156, 188,
       130, 162, 146, 178, 138, 170, 154, 186, 134, 166, 150, 182, 142, 174, 158, 190,    
       129, 161, 145, 177, 137, 169, 153, 185, 133, 165, 149, 181, 141, 173, 157, 189, 
       131, 163, 147, 179, 139, 171, 155, 187, 135, 167, 151, 183, 143, 175, 159, 191]   

def main():
    
    ex = wx.App()
    Example(None)
    ex.MainLoop()    

if __name__ == '__main__':
      main()   

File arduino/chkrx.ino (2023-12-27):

/*
* DL9LJ 2023-04-10
* Receiver for Christian Koppler
*                
* RF24 according to Dejan Nedelkovski, www.HowToMechatronics.com
* 
* Library: TMRh20/RF24, https://github.com/tmrh20/RF24/
*/

#include <SPI.h>
#include <nRF24L01.h>
#include <RF24.h>

RF24 radio(7, 8); // CE, CSN

const byte address[6] = "00001";
const int SCK_PIN = 4; // Clock pin
const int MOSI_PIN = 5; // Data out pin
const int SS_PIN = 6; // Slave select pin
const int STROBE = 3; // Strobe
byte cap = 0;
byte ind = 0;


void setup() {
  SPI.begin();
  SPI.setDataMode(SPI_MODE0);
  
  Serial.begin(9600);
  radio.begin();
  radio.openReadingPipe(0, address);
  radio.setPALevel(RF24_PA_LOW); // MIN
  radio.startListening();
  pinMode(SCK_PIN, OUTPUT);
  pinMode(MOSI_PIN, OUTPUT);
  pinMode(SS_PIN, OUTPUT);
  pinMode(STROBE, OUTPUT);
}

void loop() {

      
  if (radio.available()) {
    char text[32] = "";
    radio.read(&text, sizeof(text));
    Serial.println(text);

    switch(text[0]) {

        case 0x31:
         cap = text[3] - 0x30;
         cap = cap + (text[2] - 0x30)*10;
         cap = cap + (text[1] - 0x30)*100;
         break;

        case 0x32:
         ind = text[3] - 0x30;
         ind = ind + (text[2] - 0x30)*10;
         ind = ind + (text[1] - 0x30)*100;
         break;

        default: 
        break;
        }
      
    digitalWrite(SS_PIN, LOW);
    digitalWrite(STROBE, LOW);

    for (int i = 0; i < 15; i++) {
    // Send the current bit
      digitalWrite(MOSI_PIN, 0);
    
    // Pulse the clock
      digitalWrite(SCK_PIN, HIGH);
      digitalWrite(SCK_PIN, LOW);
    }

    for (int i = 0; i < 7; i++) {
    // Send the current bit
      digitalWrite(MOSI_PIN, bitRead(cap, i));
    
    // Pulse the clock
      digitalWrite(SCK_PIN, HIGH);
      digitalWrite(SCK_PIN, LOW);
    }

    for (int i = 0; i < 2; i++) {
    // Send the current bit
      digitalWrite(MOSI_PIN, 0);
    
    // Pulse the clock
      digitalWrite(SCK_PIN, HIGH);
      digitalWrite(SCK_PIN, LOW);
    }

    for (int i = 0; i < 7; i++) {
    // Send the current bit
      digitalWrite(MOSI_PIN, bitRead(ind, i));
    
    // Pulse the clock
      digitalWrite(SCK_PIN, HIGH);
      digitalWrite(SCK_PIN, LOW);
    }

      digitalWrite(MOSI_PIN, 0);
    
    // Pulse the clock
      digitalWrite(SCK_PIN, HIGH);
      digitalWrite(SCK_PIN, LOW);

     digitalWrite(SS_PIN, HIGH);
     digitalWrite(STROBE, LOW);
     digitalWrite(STROBE, HIGH);
     digitalWrite(STROBE, HIGH);
     digitalWrite(STROBE, LOW);
  }

}
